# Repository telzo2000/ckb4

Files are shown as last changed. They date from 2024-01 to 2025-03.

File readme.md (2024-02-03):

# ckb4

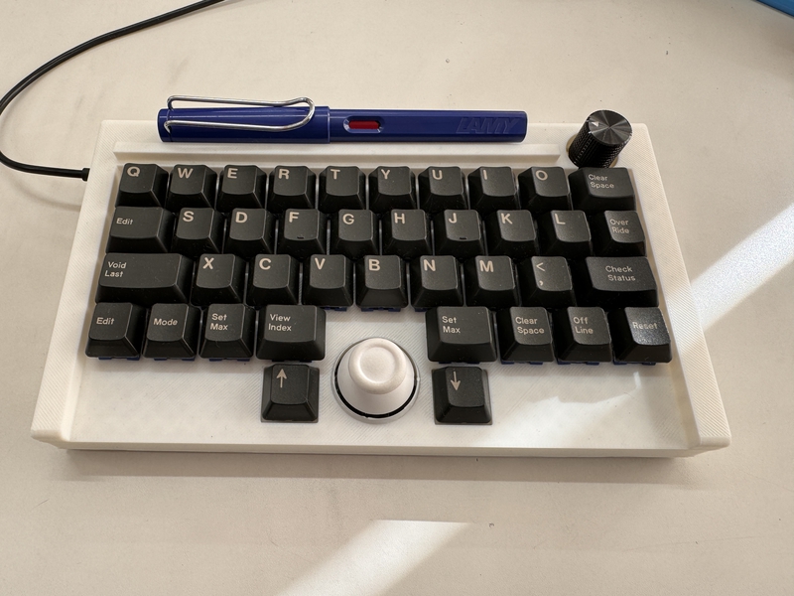
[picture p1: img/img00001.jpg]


## What is ckb4?

ckb4 is a small keyboard with qaz layout.
<br>
ckb4 has one joystick and one rotally encoder.
<br>
ckb4 use RP2040-Zero,run qmk_firmware.
<br>
<br>

## firmware

[vial](https://get.vial.today/) is possible.
<br>

## build guide

https://github.com/telzo2000/ckb4/blob/main/buildguide_for_ckb4.md

## parts list

| No. | Patrs | Quantity | remarks | Suppliers | Cost |
|--|--|--|--|--|--|
|番号|名前|数|備考|調達先|参考価格（送料込）|<br>
|1|PCB|1|QAZLayout|[elecrow](https://www.elecrow.com)<br>[JLCPCB](https://jlcpcb.com)<br>[ALLPCB](https://www.allpcb.com)|５枚で20〜30ドル|<br>
|2|RP-2040Zero|1||[Talp Keyboard](https://talpkeyboard.net)|450円|
|3|Swith socket<br>スイッチソケット|37|cherry MX互換|[遊舎工房](https://yushakobo.jp)<br>[Talp Keyboard](https://talpkeyboard.net)<br>[Daily Craft Keyboard](https://shop.dailycraft.jp)等|10個で165円程度|
|4|Switch socket<br>スイッチソケット|2|Kailh choc互換|[遊舎工房](https://yushakobo.jp)<br>[Talp Keyboard](https://talpkeyboard.net)<br>[Daily Craft Keyboard](https://shop.dailycraft.jp)等|10個で165円程度|
|5|Diode<br>ダイオード|40|リードタイプでもSMDでも可|[遊舎工房](https://yushakobo.jp)<br>[Talp Keyboard](https://talpkeyboard.net)<br>[Daily Craft Keyboard](https://shop.dailycraft.jp)等|100個で220円程度から|
|6|Rotaly Encoder<br>ロータリーエンコーダー|1|EC12互換、背の高いもの|[Daily Craft Keyboard](https://shop.dailycraft.jp)等|300円|
|7|Joystick|1|RKJXV122400R|[秋月電子](https://akizukidenshi.com/catalog/g/g115951/)|190円|
|8|TopCase|1|3D Print|||
|9|BottomCase|1|3D Print||

In addition, you will need a USB cable, keycaps, etc.
<br>
この他に、USBケーブル、キーキャップ等が必要です。
<br>

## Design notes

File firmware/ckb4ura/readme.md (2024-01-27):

# ckb4

ckb4

*A short description of the keyboard/project*

* Keyboard Maintainer: [m.ki](https://github.com/telzo2000)
* Hardware Supported: *The PCBs, controllers supported*
* Hardware Availability: *Links to where you can find this hardware*

Make example for this keyboard (after setting up your build environment):

    make ckb4:default

Flashing example for this keyboard:

    make ckb4:default:flash

See the [build environment setup](https://docs.qmk.fm/#/getting_started_build_tools) and the [make instructions](https://docs.qmk.fm/#/getting_started_make_guide) for more information. Brand new to QMK? Start with our [Complete Newbs Guide](https://docs.qmk.fm/#/newbs).

## Bootloader

Enter the bootloader in 3 ways:

* **Bootmagic reset**: Hold down the key at (0,0) in the matrix (usually the top left key or Escape) and plug in the keyboard
* **Physical reset button**: Briefly press the button on the back of the PCB - some may have pads you must short instead
* **Keycode in layout**: Press the key mapped to `QK_BOOT` if it is available

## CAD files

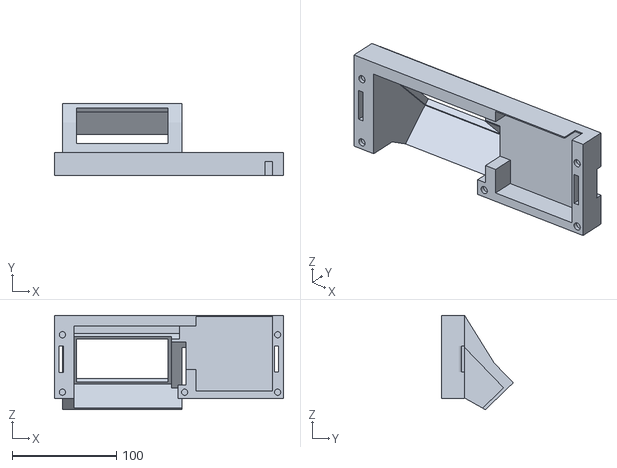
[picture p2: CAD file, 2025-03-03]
case_design/ccd001_case/cyberdeck001_topcase v9.stl
219.2 x 68.5 x 90.4

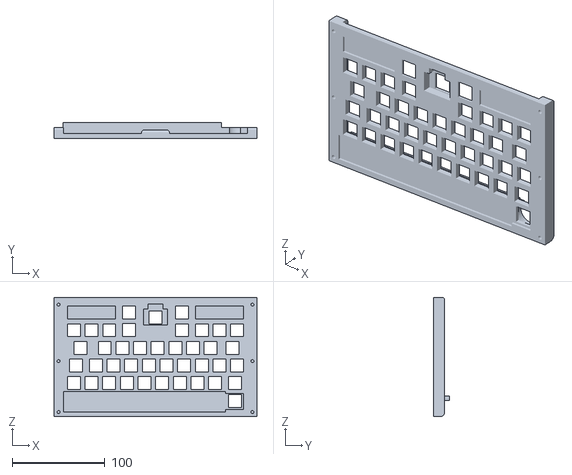
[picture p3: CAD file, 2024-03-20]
case_design/ckb4ura_model/ckb4_ura_case_another v12.stl
219.2 x 17.0 x 129.0

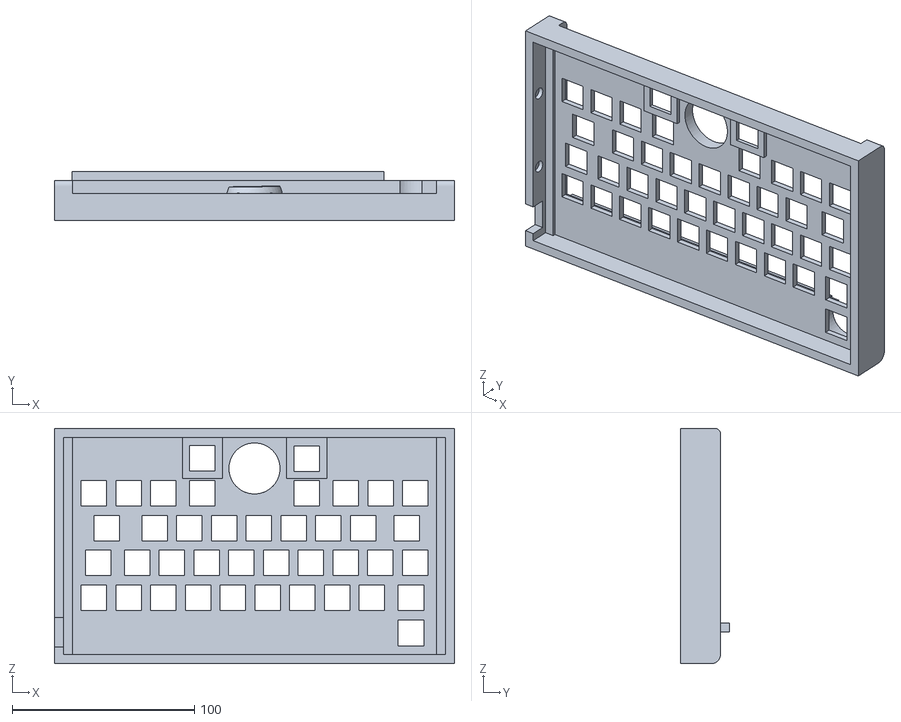
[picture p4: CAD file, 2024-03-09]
case_design/keecket_model/stl/ckb_case_top v18.stl
219.2 x 27.0 x 129.0

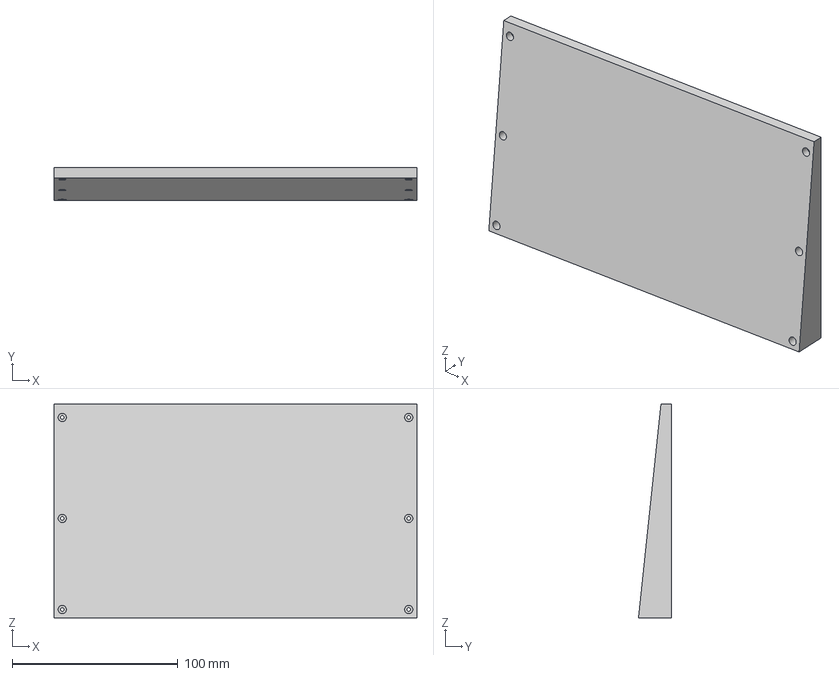
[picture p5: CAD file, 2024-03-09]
case_design/prototype/step/ckb_case_another_bottom v3.step
219.2 x 20.0 x 129.0 mm

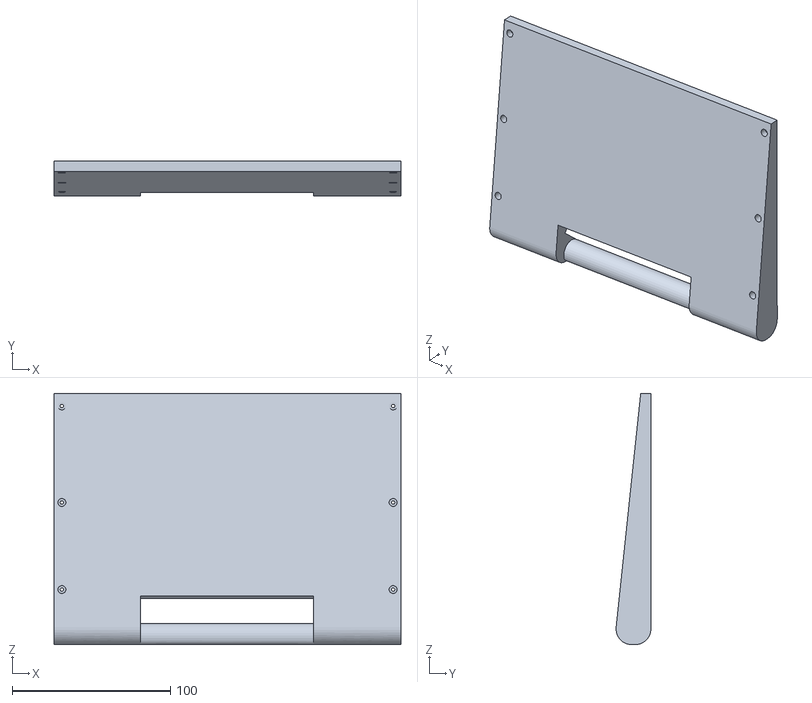
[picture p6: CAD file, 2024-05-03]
case_design/ccd001_case/ckb_case_another_bottom_ipad v4.stl
219.2 x 22.0 x 158.8

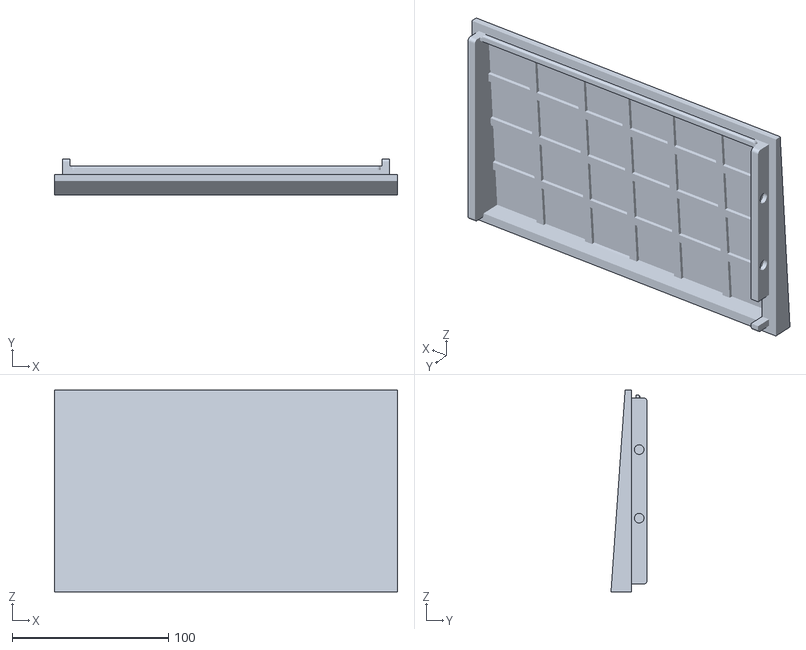
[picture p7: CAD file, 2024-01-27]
case_design/keecket_model/stl/ckb_case_bottom v6.stl
219.2 x 23.0 x 129.0

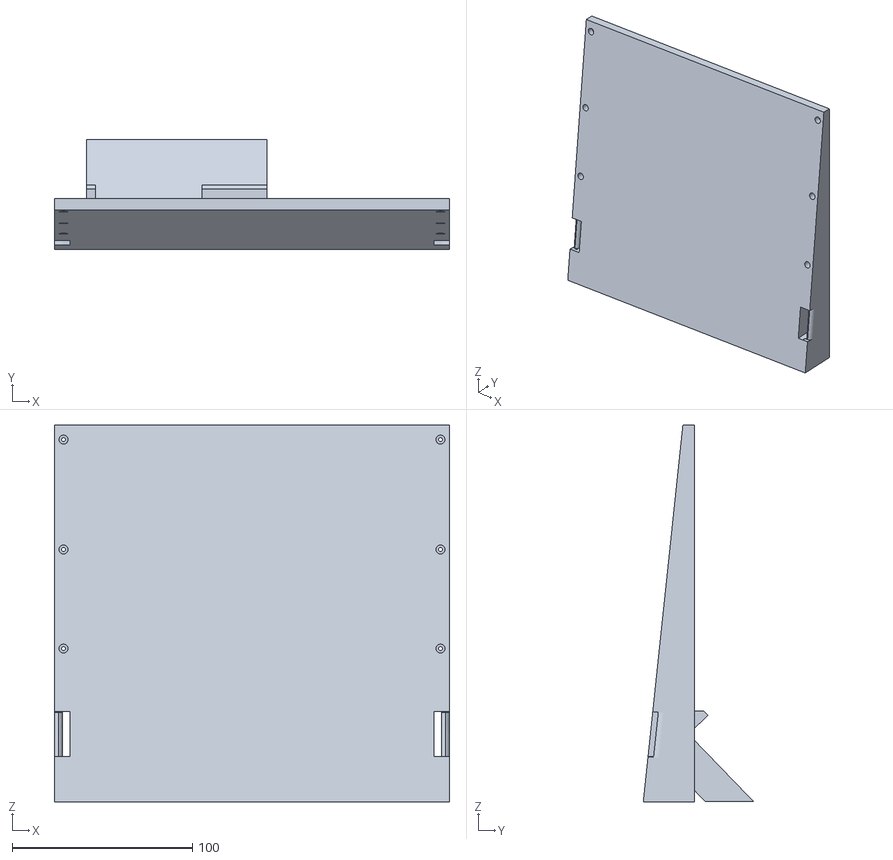
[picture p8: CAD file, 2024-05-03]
case_design/ccd001_case/cyberdeck001_bottomcase v8.stl
219.2 x 61.3 x 209.0

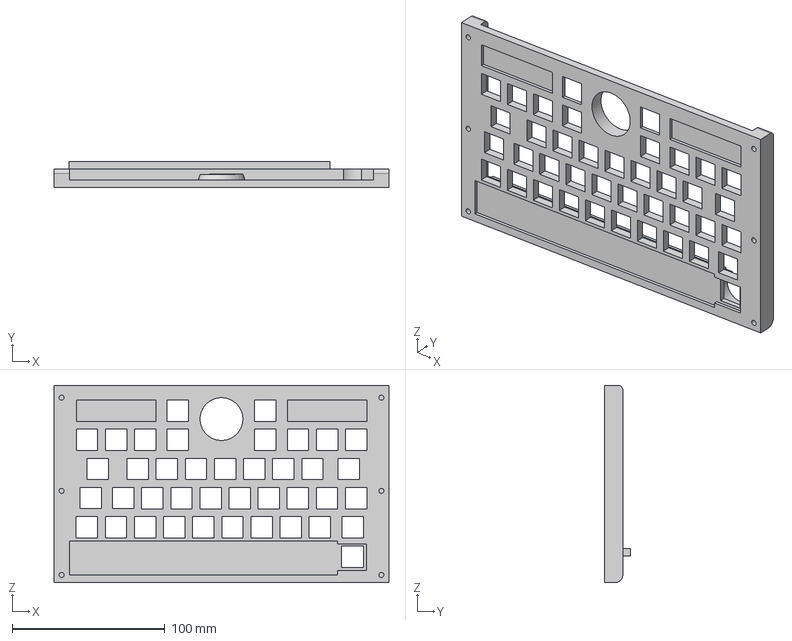
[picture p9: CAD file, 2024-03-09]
case_design/prototype/step/ckb_case_another v9.step
219.2 x 17.0 x 129.0 mm

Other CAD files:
case_design/step/ckb_case_top v13_sideline_model.step
case_design/ckb4ura_model/ckb4_ura_case_another v11.stl
case_design/prototype/step/ckb_case_another_bottom v2.step
case_design/prototype/stl/ckb_case_another v9.stl
case_design/prototype/stl/ckb_case_another_bottom v2.stl
case_design/prototype/stl/ckb_case_another_bottom v3.stl

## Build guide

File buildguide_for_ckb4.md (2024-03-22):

## Build guide

## Firmware

###  QMK_FIRMWARE

参考<br>

https://github.com/telzo2000/Hello_keyboard/blob/main/readme_about_firmware.md

[Here](https://github.com/telzo2000/ckb4/tree/main/firmware)

<br>

[vial](https://get.vial.today/) is possible.

<br>

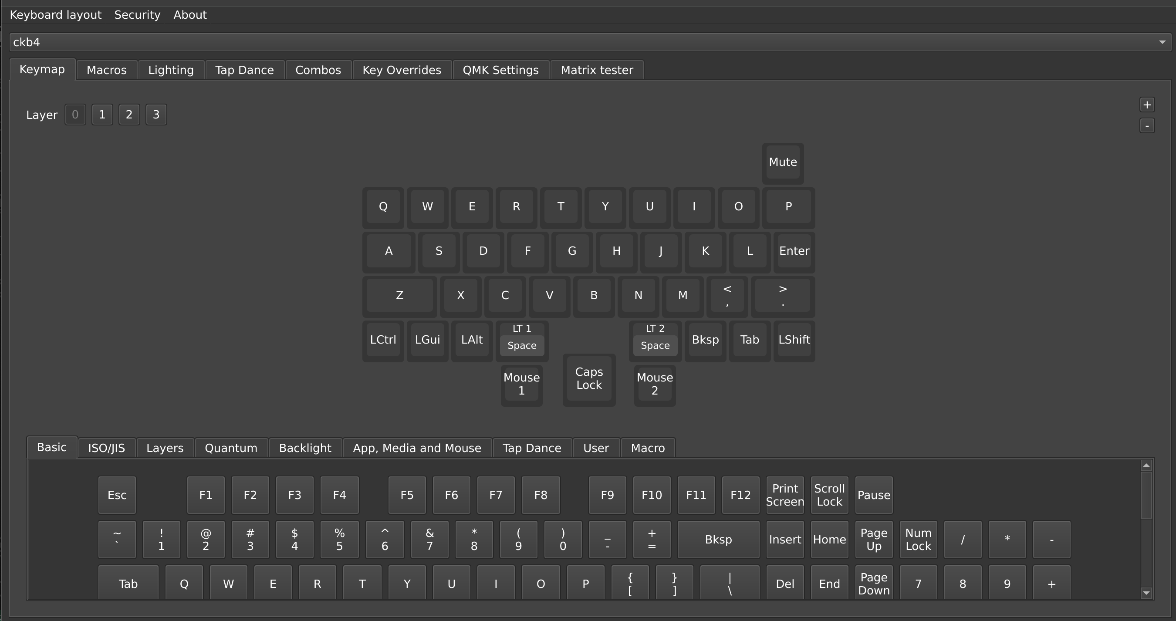
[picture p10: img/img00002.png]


## Build 1

### 1 Diode soldering

[movie](https://www.youtube.com/watch?v=Ccrc7-rJzww)

Solder the diodes to the back of PCB.
<br>
PCBの裏面にダイオードのハンダ付けをします。
<br>
There are lead type and SMD diodes.
<br>
ダイオードはリードタイプか、SMDがあります。
<br>
Here, we will explain the lead type soldering.
<br>
ここでは、リードタイプのハンダ付けの説明をします。
<br>

Use a lead bender to bend the legs of the diode.
<br>
リードベンダーを使い、ダイオードの足を曲げます。
<br>

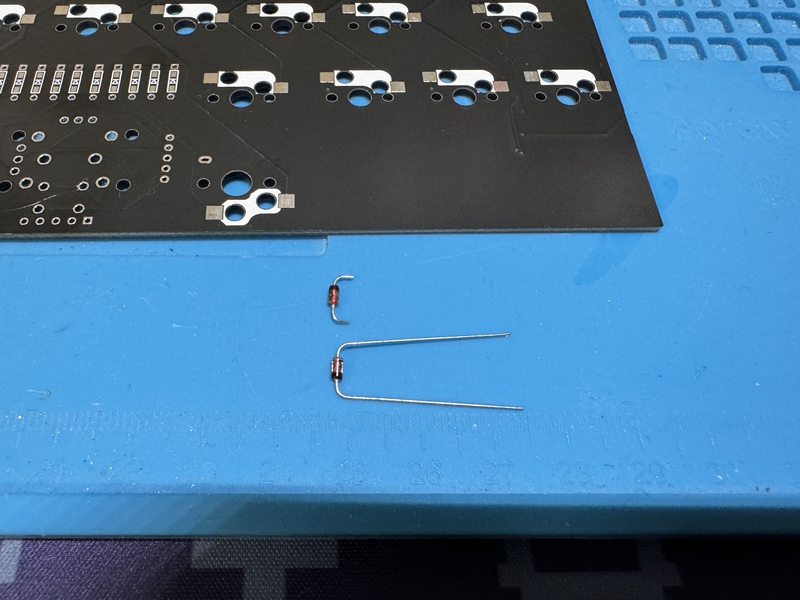
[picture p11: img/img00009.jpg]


Cut the diode leads first as shown in the photo above.
<br>

上の写真のように、先にダイオードのリードを切ってください。
<br>

Insert the diode into the board.
<br>
ダイオードを基板に挿しこみます。
<br>

Please pay attention to the orientation of the diode.
<br>
ダイオードの向きに注意してください。
<br>

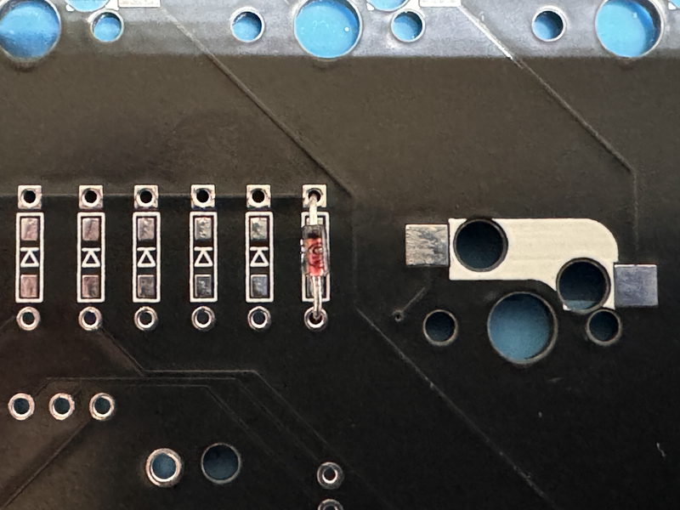
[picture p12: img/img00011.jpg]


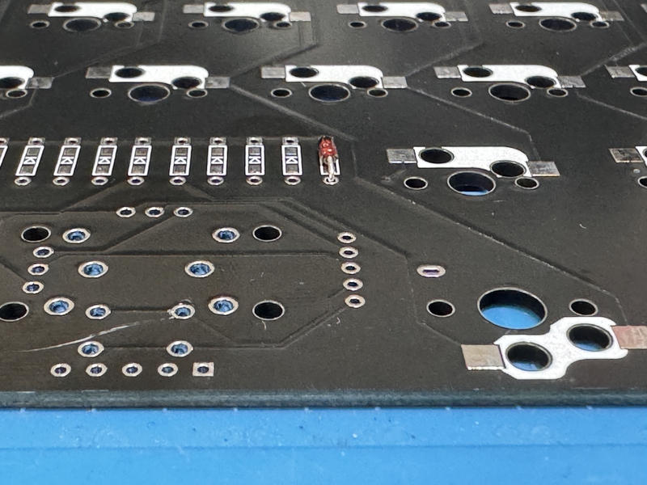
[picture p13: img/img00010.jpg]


Please solder.
<br>
はんだ付けをしてください。
<br>

[８倍速　Diodeハンダ付け動画](https://youtu.be/Yaodh2-XxV4)

<br>
<br>

### 2 Soldering switch sockets

[movie](https://www.youtube.com/watch?v=B_qjJxccLHA)

Solder the switch sockets on the back side.
<br>
裏面にスイッチソケットのハンダ付けをします。
<br>

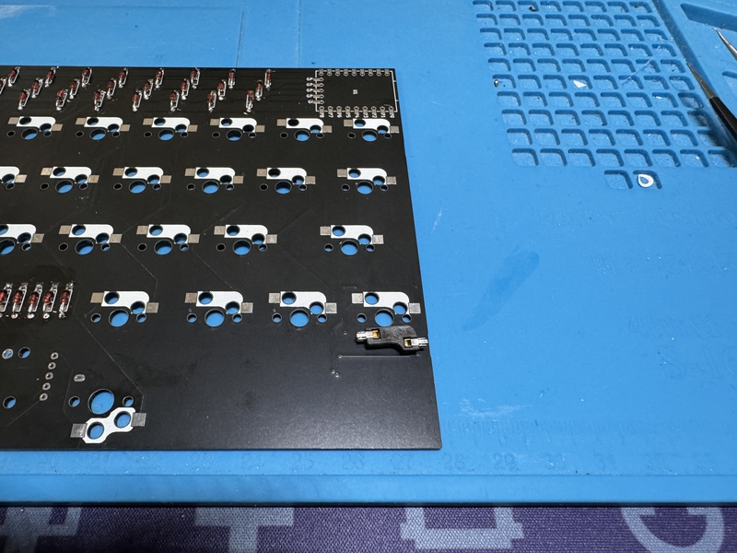
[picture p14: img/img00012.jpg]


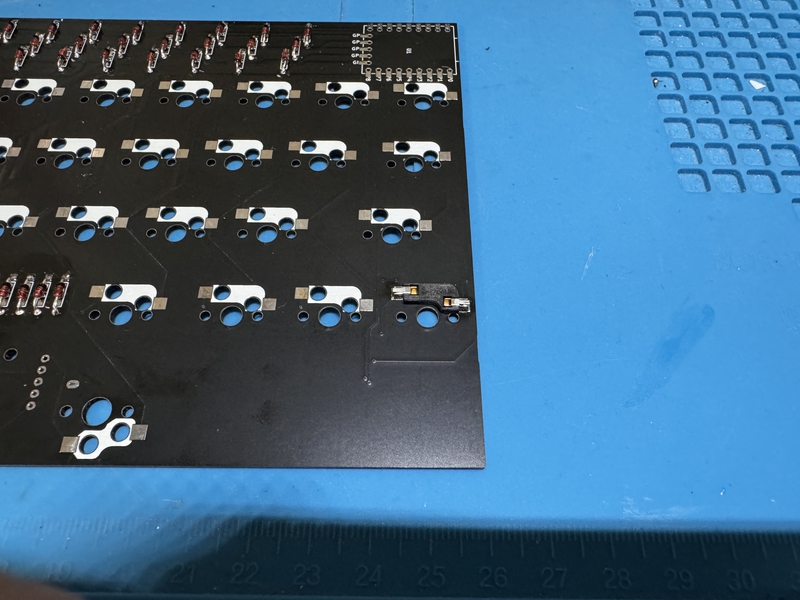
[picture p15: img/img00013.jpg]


[８倍速　Switch socketハンダ付け動画](https://youtu.be/E__mHvmIXQo)

<br><br>

### 3　Soldering RP-2040Zero  

The side on which components such as the boot button and reset button of RP-2040Zero are mounted is the front side, and the other side is the back side.
<br>
RP-2040Zeroのbootボタンやresetボタンなど部品実装されている面を表面とし、反対側を裏面とします。
<br>
Place the back side of the PCB and the back side of the RP-2040Zero facing each other and solder the respective terminals.
<br>
PCBの裏面とRP-2040Zeroの裏面が向かい合うようにして置き、それぞれの端子をハンダ付けします。
<br>
<br>

### 4 Soldering Joystick and Rotaly encodaer

Insert the joystick or rotary encoder from the front side of the PCB and solder it on the back side of the PCB.
<br>
PCB表面から、ジョイスティックやロータリーエンコーダーを差し込み、PCB裏面ではんだ付けをします。

<br><br>

### 5 Instorlling QMK＿Firmware

Install QMK_Firmware from your PC to RP-2040Zero.
<br>
QMK_FirmwareをPCからRP-2040Zeroにインストールしてください。
<br>
<br>
① Download https://github.com/telzo2000/ckb4/blob/main/firmware/ckb4_vial.uf2 to your PC.
<br>
① https://github.com/telzo2000/ckb4/blob/main/firmware/ckb4_vial.uf2　をPCにダウンロードしておく。

<br><br>
② Connect the PC and RP-2040Zero with a USB cable.
<br>
②PCとRP-2040ZeroをUSBケーブルで繋ぐ。
<br><br>
③Press the reset button while pressing the boost button on the RP-2040Zero.
<br>
③RP-2040Zeroのboostボタン押しながら、resetボタンを押す。
<br><br>
④Since there is a folder of RP-2040Zero on the PC screen, drag and drop the downloaded ckb4_vial.uf2 there.
<br>
④PC画面にはRP-2040Zeroのフォルダがあるので、そこに、ダウンロードしたckb4_vial.uf2をドラッグアンドドロップする。
<br><br>

⑤Check if it is recognized by connecting to [vial](https://get.vial.today/). Edit the keymap accordingly.
<br>
⑤[vial](https://get.vial.today/)に繋いで認識するかどうか確認する。合わせてキーマップの編集をする。

## Build 2a(prototype_case)

[movie](https://www.youtube.com/watch?v=uL3kOORdtyU)

With the bottom side of the top case facing up, heat seal the insert nuts in 6 locations using a soldering iron.
<br>
トップケースの下側を表面にし、インサートナットを６箇所に、はんだゴテで熱封入します。
<br>
<br>
Insert a 6mm M2 screw from the bottom of the bottom case to secure the top case and bottom case.
<br>
ボトムケースの下側から、M2ネジ6mmを差し込み、トップケースとボトムケースを固定します。
<br>
<br>

## Build 2b(keecke_type_case)

Insert the switch into the top case from above and secure it with the PCB switch socket from the bottom of the top case.
<br>
トップケースに上からスイッチを差し込み、トップケースの下側からPCBのスイッチソケットで固定する。
<br><br>

After inserting all the key switches, attach the rotary encoder knob and joystick cap.
<br>
すべてのキースイッチを差し込んだ後、ロータリーエンコーダーのノブやジョイスティックのキャップを装着する。
<br><br>

Fix the bottom case by fitting the uneven part on the front side.
<br>

ボトムケースは、手前の凹凸部をはめ込むようにして、固定する。
<br><br>
If necessary, attach magnets to the round indentations on the sides of the top and bottom cases.
<br>
必要であれば、トップケースとボトムケースの側面の丸い窪みに磁石をつけると、よい。
<br><br>

Welcome to the world of the best keyboards.
<br>
最高のキーボードの世界にようこそ。
<br>
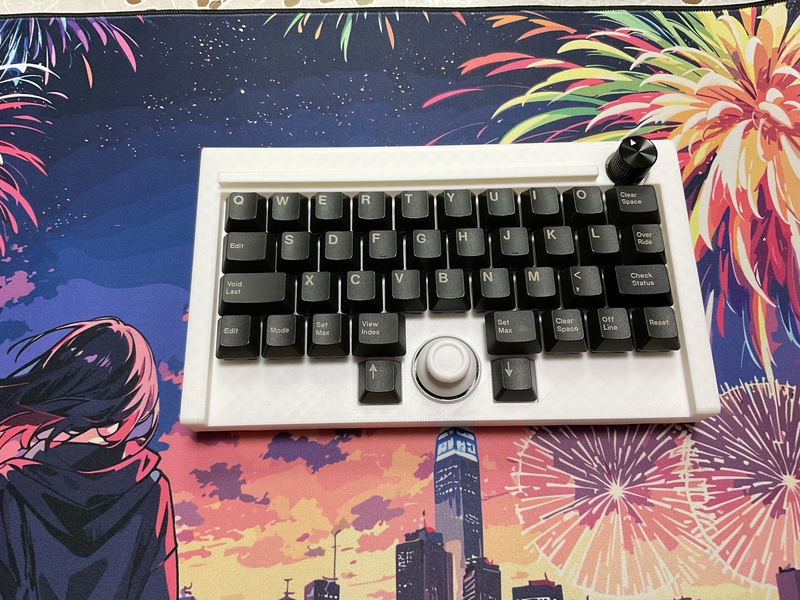
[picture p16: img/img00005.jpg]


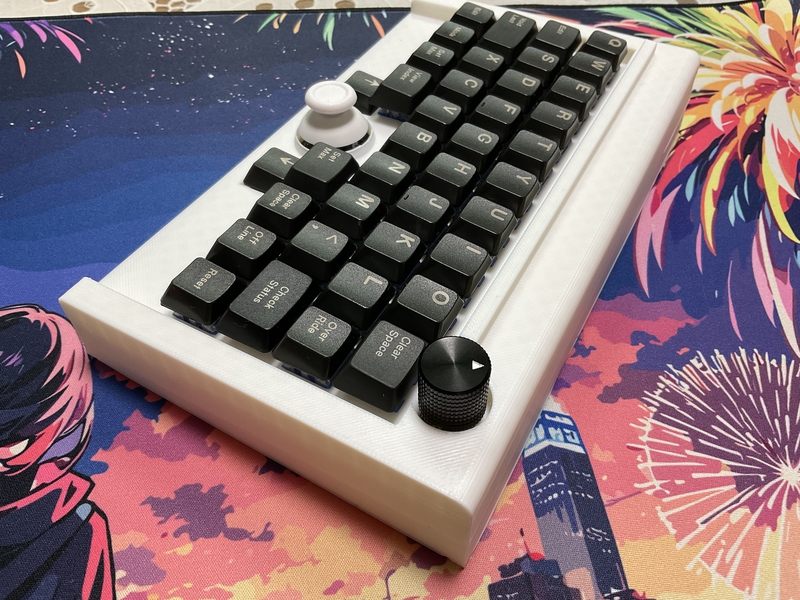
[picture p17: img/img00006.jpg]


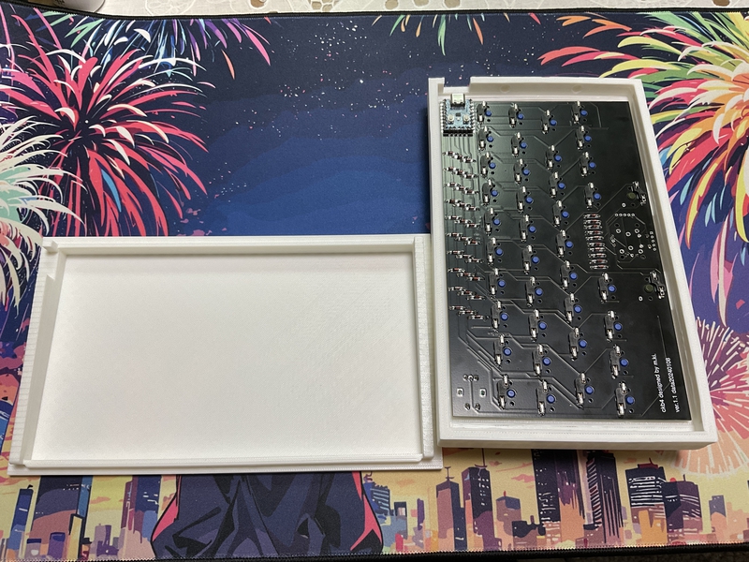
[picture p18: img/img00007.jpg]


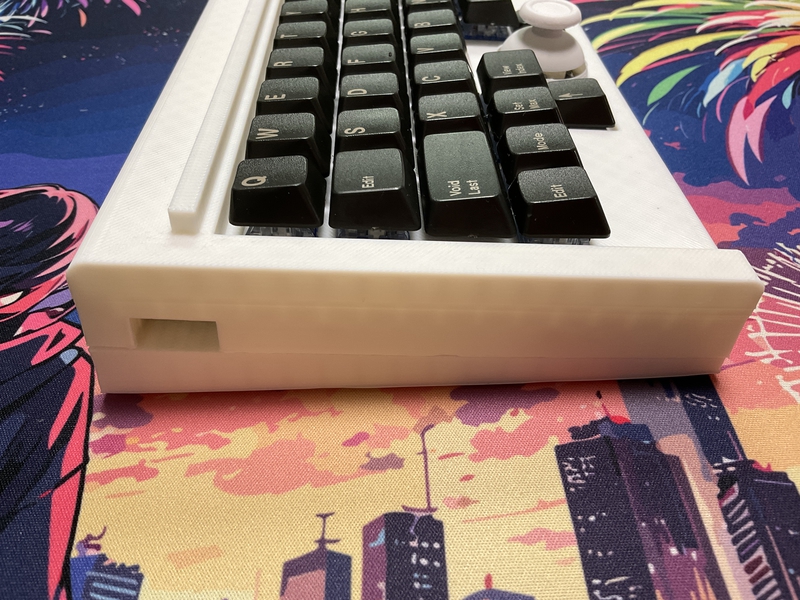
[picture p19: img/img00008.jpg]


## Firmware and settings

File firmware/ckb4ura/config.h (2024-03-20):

// Copyright 2024 m.ki (@telzo2000)
// SPDX-License-Identifier: GPL-2.0-or-later

#pragma once

/*
 * Feature disable options
 *  These options are also useful to firmware size reduction.
 */

/* disable debug print */
//#define NO_DEBUG

/* disable print */
//#define NO_PRINT

/* disable action features */
//#define NO_ACTION_LAYER
//#define NO_ACTION_TAPPING
//#define NO_ACTION_ONESHOT
#define ENCODERS_PAD_A { GP3 }
#define ENCODERS_PAD_B { GP2 }


#define I2C1_SCL_PIN GP27
#define I2C1_SDA_PIN GP26
#define I2C_DRIVER I2CD1
#define POINTING_DEVICE_ROTATION_180
#define PIMORONI_TRACKBALL_SCALE 10
#define POINTING_DEVICE_TASK_THROTTLE_MS 1

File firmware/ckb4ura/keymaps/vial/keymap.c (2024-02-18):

#include QMK_KEYBOARD_H

const uint16_t PROGMEM keymaps[][MATRIX_ROWS][MATRIX_COLS] = {
    
    [0] = LAYOUT_ortho_4x10(
        KC_Q,   KC_W,   KC_E,   KC_R,   KC_T,   KC_Y,   KC_U,   KC_I,   KC_O,   KC_P,
        KC_A,   KC_S,   KC_D,   KC_F,   KC_G,   KC_H,   KC_J,   KC_K,   KC_L,   KC_ENT,
        KC_Z,   KC_X,   KC_C,   KC_V,   KC_B,   KC_N,   KC_M,   KC_COMM,KC_DOT, 
        KC_LCTL, KC_LGUI, KC_LALT,LT(1,KC_SPC),KC_BTN1,KC_BTN2, LT(2,KC_SPC),KC_BSPC,KC_TAB,KC_LSFT,
        KC_1,
        KC_A
    ),
    [1] = LAYOUT_ortho_4x10(
        KC_1,   KC_2,   KC_3,   KC_4,   KC_5,   KC_6,   KC_7,   KC_8,   KC_9,   KC_0,
        KC_A,   KC_S,   KC_D,   KC_F,   KC_G,   KC_H,   KC_J,   KC_K,   KC_L,   KC_ENT,
        KC_Z,   KC_X,   KC_C,   KC_V,   KC_B,   KC_N,   KC_M,   KC_COMM,KC_DOT, 
        KC_LCTL, KC_LGUI, KC_LALT,KC_NO,KC_LNG2,KC_LNG1, LT(2,KC_SPC),KC_BSPC,KC_TAB,TO(3),
        KC_2,
        TO(0)
    ),
        [2] = LAYOUT_ortho_4x10(
        KC_Q,   KC_W,   KC_E,   KC_R,   KC_T,   KC_Y,   KC_U,   KC_I,   KC_O,   KC_P,
        KC_A,   KC_S,   KC_D,   KC_F,   KC_G,   KC_H,   KC_J,   KC_K,   KC_L,   KC_ENT,
        KC_Z,   KC_X,   KC_C,   KC_V,   KC_B,   KC_N,   KC_M,   KC_COMM,KC_DOT, 
        KC_LCTL, KC_LGUI, KC_LALT,LT(1,KC_SPC),KC_BTN1,KC_BTN2, KC_NO,KC_BSPC,KC_TAB,KC_LSFT,
        KC_3,
        TO(0)
    ),
        [3] = LAYOUT_ortho_4x10(
        KC_Q,   KC_W,   KC_E,   KC_R,   KC_T,   KC_Y,   KC_U,   KC_I,   KC_O,   KC_P,
        KC_A,   KC_S,   KC_D,   KC_F,   KC_G,   KC_H,   KC_J,   KC_K,   KC_L,   KC_ENT,
        KC_Z,   KC_X,   KC_C,   KC_V,   KC_B,   KC_N,   KC_M,   KC_COMM,KC_DOT, 
        KC_LCTL, KC_LGUI, KC_LALT,LT(1,KC_SPC),KC_BTN1,KC_BTN2, LT(2,KC_SPC),KC_BSPC,KC_TAB,TO(0),
        KC_4,
        TO(0)
    )

};

#if defined(ENCODER_MAP_ENABLE)
const uint16_t PROGMEM encoder_map[][NUM_ENCODERS][2] = {
    [0] = { ENCODER_CCW_CW(KC_WH_U, KC_WH_D)},
    [1] = { ENCODER_CCW_CW(KC_WH_L, KC_WH_R)},
    [2] = { ENCODER_CCW_CW(KC_KB_VOLUME_UP, KC_KB_VOLUME_DOWN)},
    [3] = { ENCODER_CCW_CW(KC_C, KC_D)},
};
#endif
